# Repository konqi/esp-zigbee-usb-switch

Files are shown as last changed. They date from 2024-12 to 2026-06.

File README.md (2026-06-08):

# zigbee-usb-switch

This project adds zigbee functionality to a USB-Switch.
I used an [ATEN US234](https://www.aten.com/global/en/products/usb-solutions/docks-and-switches/us234/) which you can get on amazon or wherever.
I used this device because it is spacious enough on the inside to fit all the additional components into the case. Other devices should work, but might not be as comfortable to solder and fit everything inside.

# Part List

- A USB Switch that has a toggle button and an LED for each channel. I used [this one](https://www.aten.com/global/en/products/usb-solutions/docks-and-switches/us234/)
- An [Espressif ESP32-C6 DevKitC](https://docs.espressif.com/projects/esp-dev-kits/en/latest/esp32c6/esp32-c6-devkitc-1/user_guide.html#). You can get those very cheap on AliExpress. I recommend you get at least two. One for the finished product, one for the prototyping breadboard.
- (for prototyping) a breadboard and jumper cables
- 3 optocouplers. I used one one LTV827 and one LTV817
- 3 resistors. Depending on your optocoupler and usb switch. I used 330 Ohm for everything
- PCB Board (6x4 cm / 20x14). I used the one from [this set](https://www.az-delivery.de/en/products/pcb-board-set-lochrasterplatte-platine-leiterplatte-4x4-stuck)

# Electronics

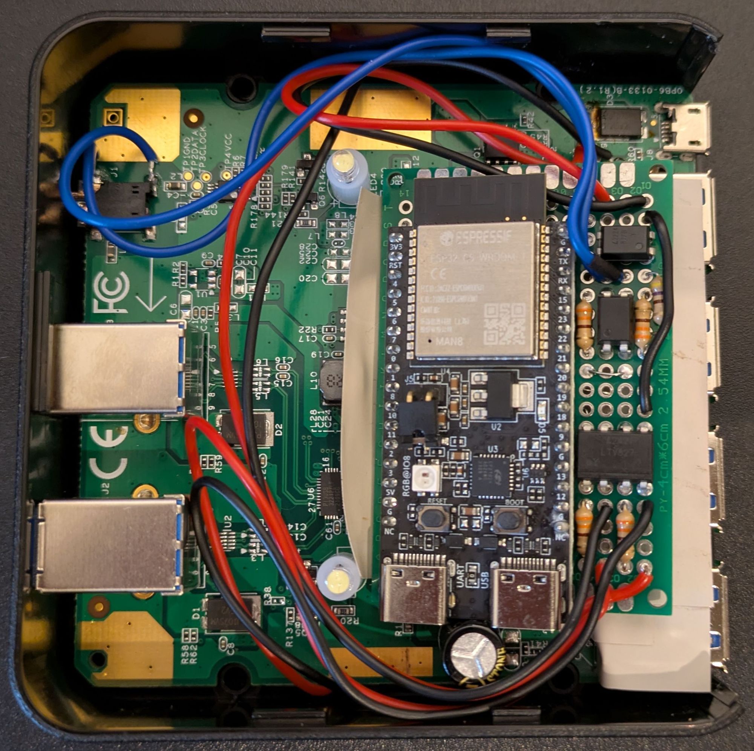
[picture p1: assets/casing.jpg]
casing


Everything fits into the original case. I clipped off everything on the back and put isolating tape wherever physical contact is possible. The two LED sockets and the condensator hold the board in place quite nicely.

## Logic wires

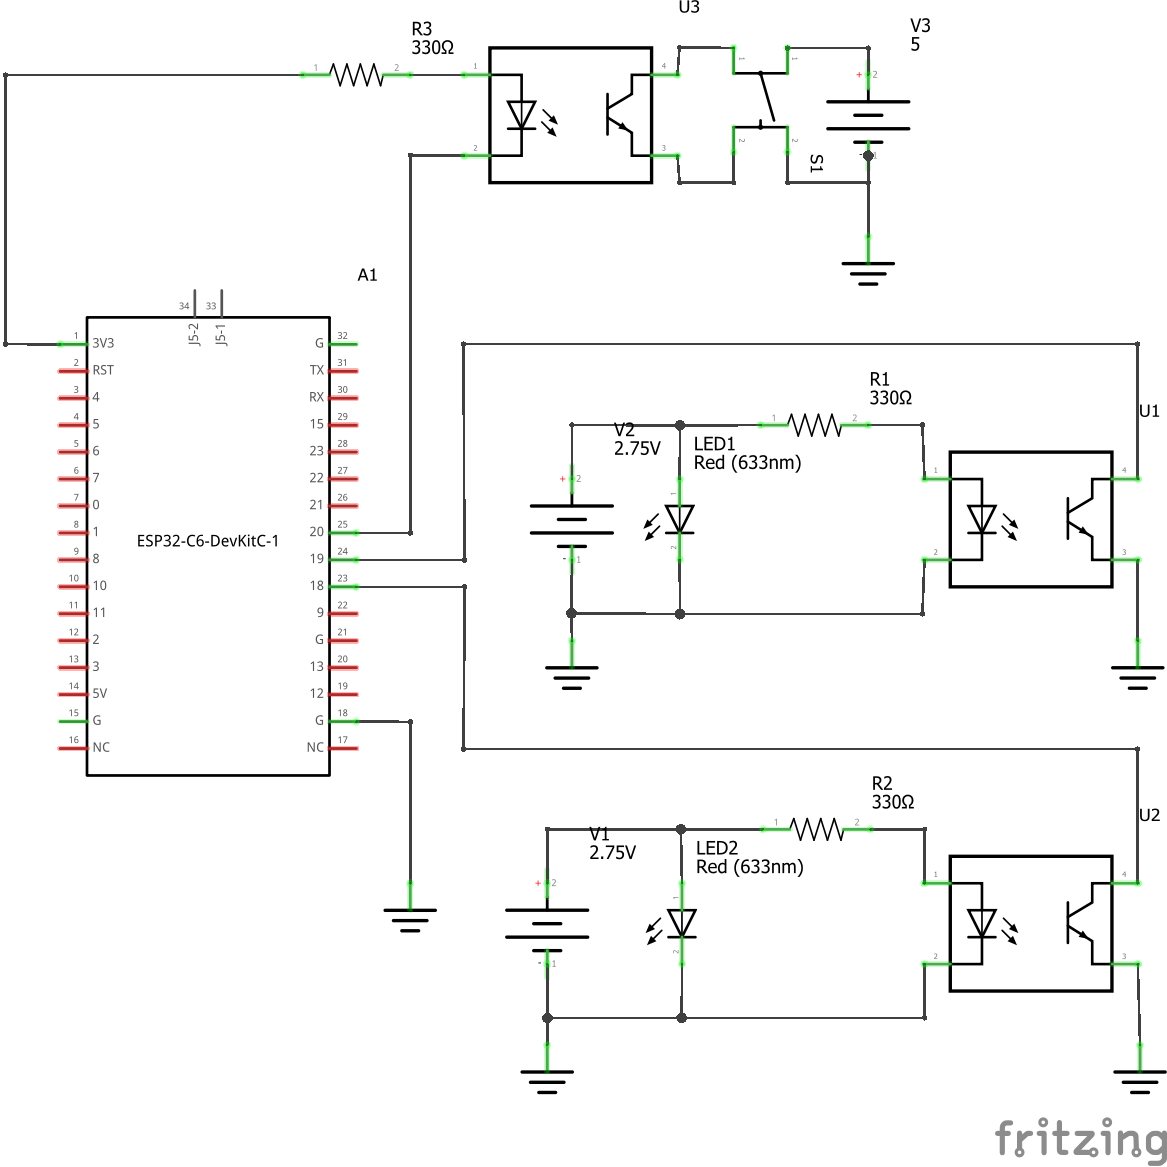
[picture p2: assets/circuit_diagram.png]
circuit diagram


Here is a [Fritzing Schematic](./assets/zigbee-usb-switch.fzz).
You can get the Fritzing App [here](https://fritzing.org/) or [here](https://github.com/fritzing/fritzing-app/releases)

**Note:**
There are a couple of parts in the schematic that represent components on the USB-Switch board:

- LEDs and their corresponding power source are the actual LEDs on the usb switch pcb board. You will need to solder wires to the led pins.
- The button and its power source are in reality a 2,5mm headphone jack on the pcb board

The switch is connected like this:

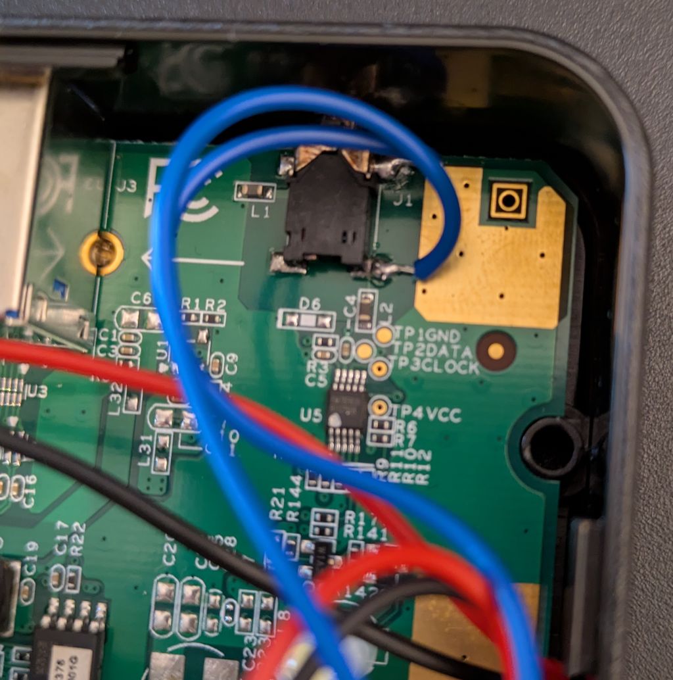
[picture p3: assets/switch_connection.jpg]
switch connect


Current flows from the bottom to the top contact. Make sure that the top pin is connected to the collector of the optocoupler and the lower one to the emitter.

## Power supply

My USB-Switch allows an external power source. I soldered a wire to the copper behind the voltage regulator on the switch pcb. I had to scrape off a bit of coating - seemed easiert than ruining the voltage regulator at the time (my soldering iron is really cheap). Connect the 5V wire to the 5V pin of the ESP32 devkit board.

I soldered ground to the base of one of the USB-Ports, but there are many options for ground. Connect ground to any of the G pins of the ESP32 devkit board.

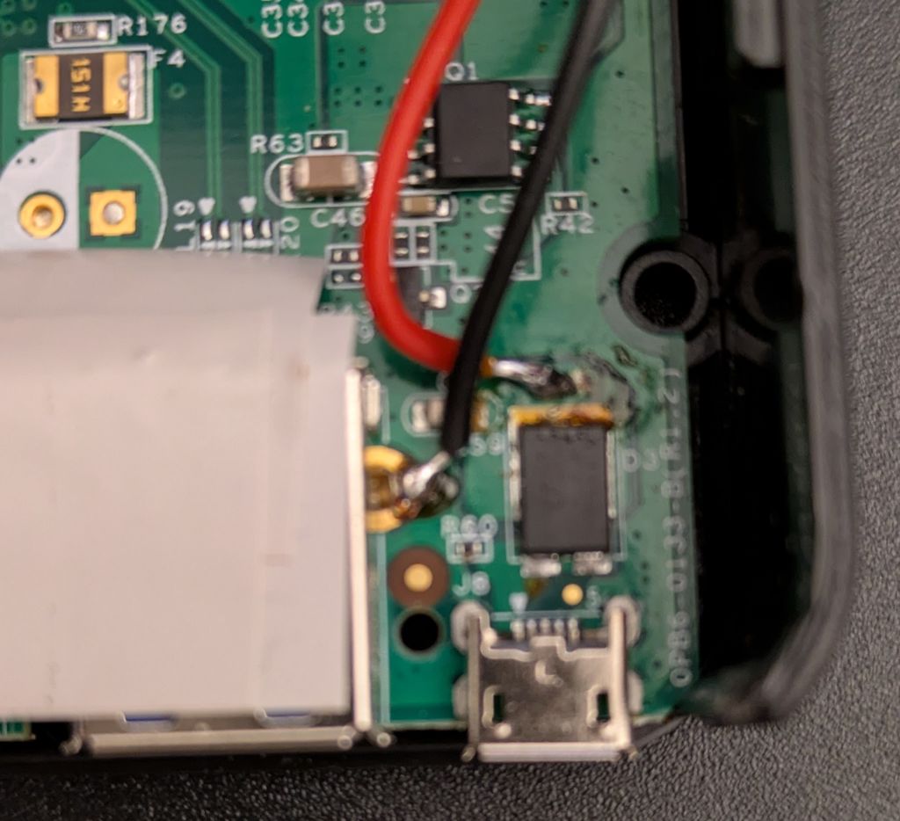
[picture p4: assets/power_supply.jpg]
power supply


# Building and Flashing

Follow the instructions provided by Espressif [see](https://github.com/espressif/esp-zigbee-sdk/tree/main/examples/home_automation_devices/on_off_light).
Personally, I use the ESP-IDF extension in VSCode.
Connect a USB-C cable to the USB-port for programming and monitoring.

Using the cli tools the commands to build and flash should be:

```sh
idf.py set-target esp32c6
idf.py reconfigure
idf.py build
idf.py -p <PORT> flash
```

# Zigbee OTA firmware updates

This firmware is now prepared for Zigbee OTA upgrades:

- OTA client cluster is enabled on endpoint 10
- partition layout includes `ota_0` and `ota_1` slots
- bootloader rollback support is enabled (`CONFIG_BOOTLOADER_APP_ROLLBACK_ENABLE=y`)

When you want to update firmware over Zigbee in the future, you still need an OTA server in your Zigbee network (for example a coordinator/plugin that can host Zigbee OTA images).

The OTA image metadata in firmware is currently:

- manufacturer code: `0x131B`
- image type: `0x0001`
- file version: generated at build time from release/build bytes

By default, the build wiring sets `file version` as:

- app release byte: `1`
- app build byte: `git rev-list --count HEAD` modulo 256
- stack release byte: `0`
- stack build byte: `0`

which is packed as `(app_release << 24) | (app_build << 16) | (stack_release << 8) | stack_build`.

For release builds, you can override values at configure time, for example:

```sh
idf.py -D ESP_OTA_APP_RELEASE=1 -D ESP_OTA_STACK_RELEASE=0 -D ESP_OTA_STACK_BUILD=0 build
```

Your OTA server image metadata must match those values and use a higher file version for updates.

# Integration

If you're using zigbee2mqtt, you can use the converter I created.
Put the [z2m converter file](./z2m_converter/usb-switch.mjs) in your `zigbee2mqtt/data/external_converters` folder.

When this is ever used by more than just one person, I might create a pull-request in the z2m repo for general support.
Doesn't make much sense to do so if it's just me.

## Zigbee OTA updates via zigbee2mqtt

The converter already has `ota: true`. To let zigbee2mqtt find the OTA image, point it at the index file that is updated automatically by the GitHub release workflow.

Add the following to your `zigbee2mqtt/data/configuration.yaml`:

```yaml
ota:
  zigbee_ota_override_index_location: https://raw.githubusercontent.com/konqi/esp-zigbee-usb-switch/main/z2m_converter/ota-index.json
```

Restart zigbee2mqtt. The device will now appear in the **OTA** tab of the zigbee2mqtt frontend. Click **Check for updates** – if a newer firmware is available it will show up, and you can trigger the update from there.

### How releases work

Push a semver tag (e.g. `v1.2.3`) to GitHub. The release workflow will:

1. Build the firmware with OTA version bytes derived from the tag:
   - `APP_RELEASE = 1`, `APP_BUILD = 2`, `STACK_RELEASE = 3`
   - `file_version = (1 << 24) | (2 << 16) | (3 << 8) | 0`
2. Wrap the `.bin` in a Zigbee OTA image (`.ota`).
3. Create a GitHub Release and attach the `.ota` file (old releases are kept).
4. Prepend the new entry to [`z2m_converter/ota-index.json`](./z2m_converter/ota-index.json) and commit it back to `main`.

The raw URL of the index file is stable, so zigbee2mqtt will always fetch the latest list on its next OTA poll.

# Resetting the zigbee connection

Press the toggle button 10 times in short succession.

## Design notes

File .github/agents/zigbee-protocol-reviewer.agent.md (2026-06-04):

---
description: "Use when reviewing Zigbee endpoint/cluster behavior, ZCL attribute handling, reporting configuration, command flow, and firmware logic correctness without making code changes. Keywords: zigbee review, zcl review, cluster validation, endpoint mapping, attribute reporting, behavior audit."
name: "Zigbee Protocol Reviewer"
tools: [read, search, get_errors]
user-invocable: true
---
You are a read-only Zigbee protocol and firmware behavior reviewer.

Your job is to analyze code and configuration for protocol correctness, behavioral regressions, and integration risks, then return prioritized findings.

## Constraints
- DO NOT edit files.
- DO NOT execute terminal commands.
- Focus on correctness, safety, and likely runtime behavior.
- Call out uncertainty explicitly when project context is incomplete.

## Review Priorities
1. Endpoint/cluster consistency and role correctness (server/client placement).
2. ZCL attribute definitions, access permissions, default values, and update paths.
3. Command handling and callback flow for missed states or race conditions.
4. Reporting configuration, binding assumptions, and interoperability risks.
5. Error handling, retries, and boot/pairing edge cases.

## Output Format
Return:
1. Findings (ordered by severity, each with file and reason)
2. Open questions or assumptions
3. Suggested tests to validate behavior

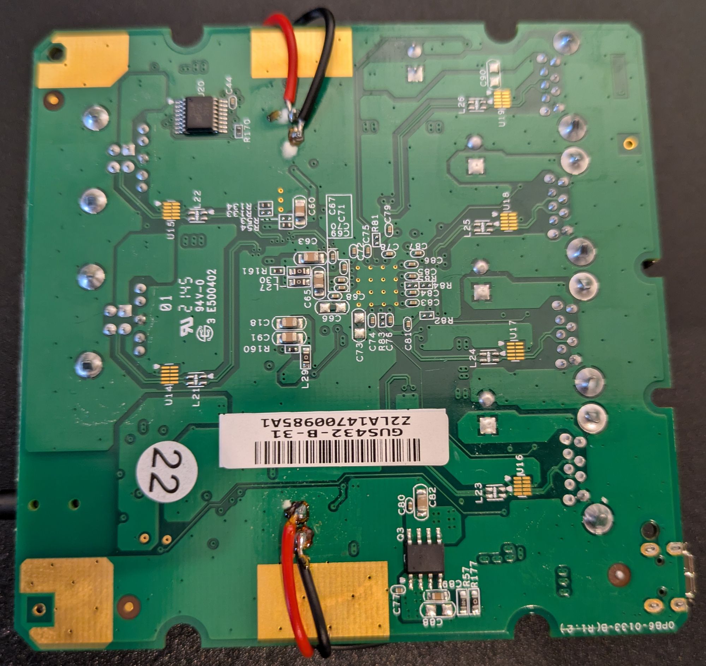
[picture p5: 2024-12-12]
assets/pcb_underside.jpg

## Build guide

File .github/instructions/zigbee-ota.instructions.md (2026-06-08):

---
description: "Reference for the Zigbee OTA update pipeline: firmware versioning, CI release workflow, z2m OTA index, and known constraints. Use when working on OTA versioning, release automation, sdkconfig, or zigbee2mqtt integration."
applyTo: "**/*.yml, z2m_converter/**, main/CMakeLists.txt, CMakeLists.txt, partitions.csv"
name: "Zigbee OTA Pipeline"
---

# Zigbee OTA Pipeline

## Overview

This project supports over-the-air firmware updates via the Zigbee OTA Upgrade cluster
(cluster ID 0x0019). Updates are delivered through zigbee2mqtt (z2m) using a custom OTA
index file hosted on GitHub.

The full pipeline is:

1. Tag is pushed → CI builds firmware → creates `.ota` file → commits updated
   `z2m_converter/ota-index.json` → publishes GitHub Release.
2. z2m polls the custom index URL and compares `fileVersion` against the device's current
   version reported over Zigbee.
3. When a newer version is found, z2m initiates OTA transfer over Zigbee.

---

## OTA File Version Packing

The 32-bit Zigbee OTA `fileVersion` is constructed by the CI release workflow from the
semver release tag `vM.m.p`:

| Byte 3 (MSB) | Byte 2 | Byte 1 | Byte 0 (LSB)  |
| --- | --- | --- | --- |
| `APP_RELEASE` = `(M<<4)\|m` | `APP_BUILD` = `p` | `STACK_RELEASE` | `STACK_BUILD` |

- **App word** (bytes 3–2) encodes major/minor/patch of the product release.
- **Stack word** (bytes 1–0) encodes the Espressif `esp-zigbee-lib` version
  (`major<<4 | minor`, patch) read from
  `managed_components/espressif__esp-zigbee-lib/idf_component.yml` at build time.

Example: tag `v0.1.5` with stack lib `1.6.8` →

```
APP_RELEASE = (0<<4)|1 = 0x01
APP_BUILD   = 5         = 0x05
STACK_RELEASE = (1<<4)|6 = 0x16
STACK_BUILD   = 8         = 0x08
fileVersion = 0x01051608
```

z2m displays this as **App: 0.1 build 5 / Stack: 1.6 build 8**.

**Limits:** major and minor each must fit in 4 bits (max 15). Patch must fit in 8 bits
(max 255). The workflow validates and fails if out of range.

---

## Version Constraints (version monotonicity)

The device only accepts an OTA upgrade if the new `fileVersion` is **numerically greater**
than its current `ota_upgrade_file_version`. Downgrades are rejected at the device level.

This means:

- Bumping major from 0 to 1 produces a massive jump in the packed integer, which is fine.
- Never reuse a version number for a different binary.
- Legacy entries in `ota-index.json` used the old byte packing scheme (raw semver bytes).
  The `create-release-tag` workflow decodes using `decode_from_new_packed` only now;
  legacy `decode_from_legacy_bytes` was removed to prevent incorrect version comparison.

---

## CMake Version Injection

`main/CMakeLists.txt` accepts CMake cache variables at configure time:

| Variable | Default | Description |
| --- | --- | --- |
| `ESP_OTA_APP_RELEASE` | 1 | Packed app release byte (major\|minor) |
| `ESP_OTA_APP_BUILD` | git commit count % 256 | App build/patch byte |
| `ESP_OTA_STACK_RELEASE` | 0 | Stack release byte |
| `ESP_OTA_STACK_BUILD` | 0 | Stack build byte |

CI passes all four explicitly. Local dev builds fall back to the git commit count for
`APP_BUILD` when not specified.

`PROJECT_VER` (CMake-level) is injected from `$ENV{PROJECT_VER}` in `CMakeLists.txt`.
CI sets it to the release tag so the boot log shows e.g. `App version: v0.1.5`.

---

## CI Workflows

### `create-release-tag.yml` (manual dispatch)

- Triggered from GitHub Actions UI with a `bump_part` dropdown: `major`, `minor`, `patch`.
- Computes next semver from max of: latest semver git tag and highest `fileVersion` in
  `ota-index.json` (decoded with the new-packed scheme only).
- Creates and pushes the tag.
- Dispatches `release.yml` via GitHub API (requires `actions: write` permission).

### `release.yml` (tag push or manual dispatch with `release_tag` input)

Steps in order:

1. **Resolve release tag** – uses pushed tag or `release_tag` input.
2. **Parse version** – decodes semver, packs `fileVersion`, validates ranges.
3. **Build firmware** – `espressif/esp-idf-ci-action@v1` with explicit `-D` overrides
   and `PROJECT_VER` env var; target: `esp32c6`; IDF version: `v6.0.1`.
4. **Download OTA image builder** – fetches `image_builder_tool.py` from
   `espressif/esp-zigbee-sdk`.
5. **Create OTA image** – wraps `.bin` in Zigbee OTA format with manufacturer code
   `0x131B` and image type `0x0001`.
6. **Compute checksum** – sha512 + file size.
7. **Fetch release notes** – reads GitHub release body via API.
8. **Update ota-index.json** – prepends new entry, deduplicates by
   `(fileVersion, imageType, manufacturerCode, modelId, manufacturerName)`.
   Adds `releaseNotes` field if release body is non-empty.
9. **Commit ota-index.json** – rebases onto `origin/main` with up to 3 push retries
   to handle concurrent pushes.
10. **Create GitHub Release** – uploads `.ota` asset, generates release notes.

Release creation happens **after** index commit to avoid publishing a stale release if
the commit step fails.

---

## OTA Index (`z2m_converter/ota-index.json`)

Served from GitHub main branch. z2m reads this via `zigbee_ota_override_index_location`
in `configuration.yaml`:

```yaml
ota:
  zigbee_ota_override_index_location: https://raw.githubusercontent.com/konqi/esp-zigbee-usb-switch/main/z2m_converter/ota-index.json
```

Each entry:

```json
{
  "fileVersion":      <uint32>,
  "fileSize":         <bytes>,
  "url":              "https://github.com/konqi/esp-zigbee-usb-switch/releases/download/<tag>/<filename>.ota",
  "imageType":        1,
  "manufacturerCode": 4891,
  "modelId":          "zigbee-usb-switch",
  "manufacturerName": "KONQI",
  "sha512":           "<hex>",
  "releaseNotes":     "<text or empty>"
}
```

`manufacturerCode 4891 = 0x131B`, `imageType 1 = 0x0001`.

---

## Firmware OTA Cluster Configuration

Defined in `main/zigbee_usb_switch.c`:

```c
esp_zb_ota_cluster_cfg_t ota_cfg = {
    .ota_upgrade_file_version = ESP_OTA_FILE_VERSION,  // from CMake
    .ota_upgrade_manufacturer = ESP_OTA_MANUFACTURER_CODE,
    .ota_upgrade_image_type   = ESP_OTA_IMAGE_TYPE,
    ...
};
esp_zb_zcl_ota_upgrade_client_variable_t ota_client_data = {
    .max_data_size = 128,  // max bytes per OTA block request
    ...
};
```

**Note:** `max_data_size` is a device-side maximum advertisement. The actual block size
used during transfer is chosen by the coordinator/z2m, not the device. In practice
z2m/coordinator sends ~50-byte blocks regardless of this setting. This is a coordinator
firmware constraint, not a firmware bug.

OTA query interval is set to `ESP_OTA_QUERY_INTERVAL_MIN` (360 minutes by default) after
joining the network.

---

## Partition Layout

`partitions.csv` defines two OTA app slots:

```
ota_0  app  ota_0  0x20000  928K
ota_1  app  ota_1           928K
```

Current app binary is ~529KB, leaving ~44% headroom. `CONFIG_BOOTLOADER_APP_ROLLBACK_ENABLE=y`
is set so rollback to previous slot is possible on boot failure.

---

## Known Constraints and Gotchas

- **OTA speed** is ~50 bytes/block × ~280ms/block ≈ 50 minutes for a 529KB image. This
  is a coordinator-side limit, not configurable from the device firmware.
- **Downgrade blocked** at device level; version must be numerically larger.
- **Tag trigger limitation**: tags pushed by GITHUB_TOKEN do not trigger `push` events in
  other workflows. This is why `create-release-tag` explicitly dispatches `release.yml`
  via API after pushing the tag.
- **Wi-Fi is disabled** in sdkconfig (not needed for Zigbee-only operation), but LWIP
  and ESP-TLS must remain enabled because transitive dependencies
  (`espressif__esp-zigbee-lib` → `openthread`) require them.
- **sdkconfig vs sdkconfig.defaults**: durable settings go in `sdkconfig.defaults`.
  Machine-generated `sdkconfig` should not be relied on for CI reproducibility.
- **Build type**: CI always builds with the exact committed `sdkconfig.defaults`. Local
  dev builds may differ if `sdkconfig` has uncommitted overrides.

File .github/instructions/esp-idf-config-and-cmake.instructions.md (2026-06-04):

---
description: "Use when editing ESP-IDF build files or configuration such as CMakeLists.txt, *.cmake, sdkconfig defaults, and related component wiring. Covers style and safety conventions for this firmware project."
applyTo: "**/CMakeLists.txt, **/*.cmake, sdkconfig, sdkconfig.defaults, sdkconfig.old"
name: "ESP-IDF Config And CMake Conventions"
---
# ESP-IDF Config and CMake Conventions

- Prefer minimal, targeted changes; avoid broad reformatting in build and config files.
- Preserve existing variable naming and ordering patterns in each CMake file.
- Keep component boundaries explicit with `idf_component_register(...)`; do not add hidden global include paths unless required.
- When adding source files, include only what is needed and keep file lists deterministic.
- Prefer project-local options over global compile definitions unless the setting must affect all components.
- For sdkconfig-related edits, document intent in commit context and avoid toggling unrelated options.
- Treat `sdkconfig.defaults` as the source of durable defaults; avoid relying on machine-specific values in `sdkconfig`.
- If a configuration change can alter flash size, partitions, or boot behavior, call out risk and require explicit validation.
- Keep comments short and practical; explain non-obvious tradeoffs only.
- After changes, validate with build before flash/monitor flows.

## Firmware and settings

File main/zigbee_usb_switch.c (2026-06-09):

/*
 * This code is based on the espressif zigbee home automation (ha) light on/off example
 * The LED ON/OFF functionality is simply left in here, because it's a great way to
 * determine if the zigbee communication works at all.
 */
#include "zigbee_usb_switch.h"
#include "esp_check.h"
#include "esp_err.h"
#include "esp_log.h"
#include "esp_system.h"
#include "nvs_flash.h"
#include "freertos/FreeRTOS.h"
#include "freertos/task.h"
#include "ha/esp_zigbee_ha_standard.h"
#include "esp_zigbee_attribute.h"
#include "ota.h"

#if !defined ZB_ED_ROLE
#error Define ZB_ED_ROLE in idf.py menuconfig to compile light (End Device) source code.
#endif

static const char *TAG = "ESP_ZB_USB_SWITCH";

#define ZB_INVALID_SHORT_ADDR 0xFFFF
#define ZB_STEERING_RETRY_BASE_DELAY_MS 2000
#define ZB_STEERING_RETRY_MAX_DELAY_MS 60000
#define ZB_STEERING_RETRY_MAX_BACKOFF_STEPS 5

#define BUILD_MONTH_IS_JAN (__DATE__[0] == 'J' && __DATE__[1] == 'a' && __DATE__[2] == 'n')
#define BUILD_MONTH_IS_FEB (__DATE__[0] == 'F')
#define BUILD_MONTH_IS_MAR (__DATE__[0] == 'M' && __DATE__[2] == 'r')
#define BUILD_MONTH_IS_APR (__DATE__[0] == 'A' && __DATE__[1] == 'p')
#define BUILD_MONTH_IS_MAY (__DATE__[0] == 'M' && __DATE__[2] == 'y')
#define BUILD_MONTH_IS_JUN (__DATE__[0] == 'J' && __DATE__[2] == 'n')
#define BUILD_MONTH_IS_JUL (__DATE__[0] == 'J' && __DATE__[2] == 'l')
#define BUILD_MONTH_IS_AUG (__DATE__[0] == 'A' && __DATE__[1] == 'u')
#define BUILD_MONTH_IS_SEP (__DATE__[0] == 'S')
#define BUILD_MONTH_IS_OCT (__DATE__[0] == 'O')
#define BUILD_MONTH_IS_NOV (__DATE__[0] == 'N')
#define BUILD_MONTH_IS_DEC (__DATE__[0] == 'D')

#define BUILD_MONTH_CH0 \
    (BUILD_MONTH_IS_OCT || BUILD_MONTH_IS_NOV || BUILD_MONTH_IS_DEC ? '1' : '0')

#define BUILD_MONTH_CH1                                  \
    (BUILD_MONTH_IS_JAN ? '1' : BUILD_MONTH_IS_FEB ? '2' \
                            : BUILD_MONTH_IS_MAR   ? '3' \
                            : BUILD_MONTH_IS_APR   ? '4' \
                            : BUILD_MONTH_IS_MAY   ? '5' \
                            : BUILD_MONTH_IS_JUN   ? '6' \
                            : BUILD_MONTH_IS_JUL   ? '7' \
                            : BUILD_MONTH_IS_AUG   ? '8' \
                            : BUILD_MONTH_IS_SEP   ? '9' \
                            : BUILD_MONTH_IS_OCT   ? '0' \
                            : BUILD_MONTH_IS_NOV   ? '1' \
                                                   : '2')

#define BUILD_DAY_CH0 (__DATE__[4] == ' ' ? '0' : __DATE__[4])
#define BUILD_DAY_CH1 (__DATE__[5])

#define BUILD_DATE_YYYYMMDD {__DATE__[7], __DATE__[8], __DATE__[9], __DATE__[10], BUILD_MONTH_CH0, BUILD_MONTH_CH1, BUILD_DAY_CH0, BUILD_DAY_CH1, '\0'}

#ifndef ESP_SW_BUILD_ID
#define ESP_SW_BUILD_ID "0.0.0"
#endif

static uint8_t s_steering_retry_attempt = 0;
static const char s_build_date_code[] = BUILD_DATE_YYYYMMDD;
static const char s_sw_build_id[] = ESP_SW_BUILD_ID;

static void fill_zcl_string(uint8_t *zb_str, size_t zb_str_size, const char *text)
{
    if (!zb_str || !text || zb_str_size < 2)
    {
        return;
    }

    size_t max_payload = zb_str_size - 1;
    size_t text_len = strlen(text);
    if (text_len > max_payload)
    {
        text_len = max_payload;
    }

    zb_str[0] = (uint8_t)text_len;
    memcpy(&zb_str[1], text, text_len);
}

static void build_basic_cluster_version_strings(uint32_t file_version, uint8_t *sw_build_id, size_t sw_build_id_size,
                                                uint8_t *date_code, size_t date_code_size)
{
    (void)file_version;
    fill_zcl_string(sw_build_id, sw_build_id_size, s_sw_build_id);
    fill_zcl_string(date_code, date_code_size, s_build_date_code);
}

// Note: On my board GPIO_NUM_21 is soldered as input to the external button.
// That experiment didn't work out but I'm too lazy to desolder the IC...
// You don't need to configure GPIO_NUM_21 if it is not connected.
const int gpio_inputs[] = {GPIO_NUM_9, GPIO_NUM_18, GPIO_NUM_19, GPIO_NUM_21};

// this only works as long as gpio_inputs is const
#define INPUT_GPIO_LEN sizeof(gpio_inputs) / sizeof(int)

typedef enum usb_switch_state_enum
{
    CH_1 = 0,
    CH_2 = 1,
    UNKNOWN = 2
} usb_switch_state_t;

static usb_switch_state_t usb_switch_state = UNKNOWN;
static uint8_t reset_counter = 0;

void reset_by_toggle(int gpio_num, gpio_input_state_t value)
{
    if (gpio_num == GPIO_NUM_18 || gpio_num == GPIO_NUM_19)
    {
        if (value == ON_LONG)
        {
            // reset counter
            reset_counter = 0;
        }
        else if (value == ON)
        {
            // increase reset counter
            ++reset_counter;

            if (reset_counter > 10)
            {
                ESP_LOGI(TAG, "Resetting device.");
                esp_zb_factory_reset();
                reset_counter = 0;
            }
        }
    }
}

static void debounced_input_handler(int gpio_num, gpio_input_state_t value)
{
    ESP_LOGI(TAG, "GPIO %i is now %i", gpio_num, value);
    // the following line can be enabled, this effectively creates a flip-flop for the inputs (good for testing connections)
    // toggle_gpio(GPIO_OUTPUT_IO_TOGGLE_SWITCH, 200);

    reset_by_toggle(gpio_num, value);

    if (value == ON)
    {
        usb_switch_state_t new_value = UNKNOWN;
        switch (gpio_num)
        {
        case GPIO_NUM_18:
            new_value = CH_2;
            break;
        case GPIO_NUM_19:
            new_value = CH_1;
            break;
        case GPIO_NUM_9:
            ESP_LOGI(TAG, "Resetting device.");
            esp_zb_factory_reset();
            break;
        default:
            ESP_LOGW(TAG, "Pressing GPIO %i isn't defined.", gpio_num);
            break;
        }

        if (new_value != UNKNOWN)
        {
            usb_switch_state = new_value;
            ESP_LOGI(TAG, "USB Switch state is now %i", new_value);

            esp_zb_lock_acquire(portMAX_DELAY);
            esp_zb_zcl_status_t status = esp_zb_zcl_set_attribute_val(HA_ESP_LIGHT_ENDPOINT,
                                                                      ESP_ZB_ZCL_CLUSTER_ID_MULTI_VALUE,
                                                                      ESP_ZB_ZCL_CLUSTER_SERVER_ROLE,
                                                                      ESP_ZB_ZCL_ATTR_MULTI_VALUE_PRESENT_VALUE_ID,
                                                                      &new_value,
                                                                      false);
            esp_zb_lock_release();
            ESP_LOGI(TAG, "Multistate value updated to %i, status %i", new_value, status);

            // manual report of attribute (not necessary)
            // esp_zb_zcl_report_attr_cmd_t report_attr_cmd = {
            //     .address_mode = ESP_ZB_APS_ADDR_MODE_DST_ADDR_ENDP_NOT_PRESENT,
            //     .clusterID = ESP_ZB_ZCL_CLUSTER_ID_MULTI_VALUE,
            //     .attributeID = ESP_ZB_ZCL_ATTR_MULTI_VALUE_PRESENT_VALUE_ID,
            //     .direction = ESP_ZB_ZCL_CMD_DIRECTION_TO_SRV, // ESP_ZB_ZCL_CMD_DIRECTION_TO_CLI,
            //     .zcl_basic_cmd.src_endpoint = HA_ESP_LIGHT_ENDPOINT,
            // };

            // esp_zb_lock_acquire(portMAX_DELAY);
            // ESP_ERROR_CHECK_WITHOUT_ABORT(esp_zb_zcl_report_attr_cmd_req(&report_attr_cmd));
            // esp_zb_lock_release();
            // ESP_LOGI(TAG, "Multistate value reported");
        }
    }
}

static esp_err_t deferred_driver_init(void)
{
    static bool is_inited = false;

    ESP_RETURN_ON_FALSE(!is_inited, ESP_OK, TAG, "Deferred driver already initialized");

    light_driver_init(LIGHT_DEFAULT_OFF);
    // ESP_RETURN_ON_FALSE(switch_driver_init(button_func_pair, PAIR_SIZE(button_func_pair), zb_buttons_handler), ESP_FAIL, TAG,
    //                     "Failed to initialize switch driver");
    ESP_LOGI(TAG, "Configuring %i pins for input", INPUT_GPIO_LEN);
    ESP_RETURN_ON_ERROR(gpio_debounce_input_init(gpio_inputs, INPUT_GPIO_LEN, debounced_input_handler), TAG, "Failed to initialize debounced inputs.");
    ESP_RETURN_ON_ERROR(toggle_driver_gpio_init(GPIO_OUTPUT_IO_TOGGLE_SWITCH), TAG,
                        "Failed to initialize toggle driver");
    is_inited = true;

    return ESP_OK;
}

static void bdb_start_top_level_commissioning_cb(uint8_t mode_mask)
{
    esp_err_t err = esp_zb_bdb_start_top_level_commissioning(mode_mask);
    if (err != ESP_OK)
    {
        ESP_LOGW(TAG, "Failed to start Zigbee commissioning (status: %s)", esp_err_to_name(err));
    }
}

static void schedule_steering_retry(const char *reason)
{
    uint32_t backoff_step = s_steering_retry_attempt;
    if (backoff_step > ZB_STEERING_RETRY_MAX_BACKOFF_STEPS)
    {
        backoff_step = ZB_STEERING_RETRY_MAX_BACKOFF_STEPS;
    }

    uint32_t delay_ms = ZB_STEERING_RETRY_BASE_DELAY_MS << backoff_step;
    if (delay_ms > ZB_STEERING_RETRY_MAX_DELAY_MS)
    {
        delay_ms = ZB_STEERING_RETRY_MAX_DELAY_MS;
    }

    ESP_LOGW(TAG, "Scheduling steering retry #%u in %lu ms (%s)",
             (unsigned int)(s_steering_retry_attempt + 1), (unsigned long)delay_ms,
             reason ? reason : "no reason");

    esp_zb_scheduler_alarm((esp_zb_callback_t)bdb_start_top_level_commissioning_cb,
                           ESP_ZB_BDB_MODE_NETWORK_STEERING,
                           delay_ms);

    if (s_steering_retry_attempt < 255)
    {
        s_steering_retry_attempt++;
    }
}

void esp_zb_app_signal_handler(esp_zb_app_signal_t *signal_struct)
{
    uint32_t *p_sg_p = signal_struct->p_app_signal;
    esp_err_t err_status = signal_struct->esp_err_status;
    esp_zb_app_signal_type_t sig_type = *p_sg_p;
    switch (sig_type)
    {
    case ESP_ZB_ZDO_SIGNAL_SKIP_STARTUP:
        ESP_LOGI(TAG, "Initialize Zigbee stack");
        esp_zb_bdb_start_top_level_commissioning(ESP_ZB_BDB_MODE_INITIALIZATION);
        break;
    case ESP_ZB_BDB_SIGNAL_DEVICE_FIRST_START:
    case ESP_ZB_BDB_SIGNAL_DEVICE_REBOOT:
        if (err_status == ESP_OK)
        {
            ESP_LOGI(TAG, "Deferred driver initialization %s", deferred_driver_init() ? "failed" : "successful");
            ESP_LOGI(TAG, "Device started up in %s factory-reset mode", esp_zb_bdb_is_factory_new() ? "" : "non");
            if (esp_zb_bdb_is_factory_new())
            {
                s_steering_retry_attempt = 0;
                ESP_LOGI(TAG, "Start network steering");
                esp_zb_bdb_start_top_level_commissioning(ESP_ZB_BDB_MODE_NETWORK_STEERING);
            }
            else
            {
                uint16_t short_addr = esp_zb_get_short_address();
                if (short_addr == ZB_INVALID_SHORT_ADDR)
                {
                    ESP_LOGW(TAG, "Device rebooted but is not joined yet, starting recovery steering");
                    schedule_steering_retry("reboot without network");
                }
                else
                {
                    s_steering_retry_attempt = 0;
                    ESP_LOGI(TAG, "Device rebooted and restored network (PAN ID: 0x%04hx, Channel:%d, Short Address: 0x%04hx)",
                             esp_zb_get_pan_id(), esp_zb_get_current_channel(), short_addr);
                    ota_configure_query_interval(HA_ESP_LIGHT_ENDPOINT);
                }
            }
        }
        else
        {
            /* commissioning failed */
            ESP_LOGW(TAG, "Failed to initialize Zigbee stack (status: %s)", esp_err_to_name(err_status));
            schedule_steering_retry("stack initialization failed");
        }
        break;
    case ESP_ZB_BDB_SIGNAL_STEERING:
        if (err_status == ESP_OK)
        {
            s_steering_retry_attempt = 0;
            esp_zb_ieee_addr_t extended_pan_id;
            esp_zb_get_extended_pan_id(extended_pan_id);
            ESP_LOGI(TAG, "Joined network successfully (Extended PAN ID: %02x:%02x:%02x:%02x:%02x:%02x:%02x:%02x, PAN ID: 0x%04hx, Channel:%d, Short Address: 0x%04hx)",
                     extended_pan_id[7], extended_pan_id[6], extended_pan_id[5], extended_pan_id[4],
                     extended_pan_id[3], extended_pan_id[2], extended_pan_id[1], extended_pan_id[0],
                     esp_zb_get_pan_id(), esp_zb_get_current_channel(), esp_zb_get_short_address());

            ota_configure_query_interval(HA_ESP_LIGHT_ENDPOINT);

            // read values once after zigbee initialization
            gpio_read_once();
        }
        else
        {
            ESP_LOGI(TAG, "Network steering was not successful (status: %s)", esp_err_to_name(err_status));
            schedule_steering_retry("network steering failed");
        }
        break;
    case ESP_ZB_ZDO_SIGNAL_DEVICE_ANNCE:
    {
        const esp_zb_zdo_signal_device_annce_params_t *dev_annce = (const esp_zb_zdo_signal_device_annce_params_t *)esp_zb_app_signal_get_params(p_sg_p);
        if (dev_annce)
        {
            ESP_LOGI(TAG, "New device commissioned or rejoined (short: 0x%04hx)", dev_annce->device_short_addr);
        }
        break;
    }
    case ESP_ZB_NWK_SIGNAL_PERMIT_JOIN_STATUS:
    {
        const uint8_t *duration = (const uint8_t *)esp_zb_app_signal_get_params(p_sg_p);
        if (duration && *duration)
        {
            ESP_LOGI(TAG, "Network(0x%04hx) is open for %d seconds", esp_zb_get_pan_id(), *duration);
        }
        else
        {
            ESP_LOGI(TAG, "Network(0x%04hx) closed, devices joining not allowed", esp_zb_get_pan_id());
        }
        break;
    }
    default:
        ESP_LOGI(TAG, "ZDO signal: %s (0x%x), status: %s", esp_zb_zdo_signal_to_string(sig_type), sig_type,
                 esp_err_to_name(err_status));
        break;
    }
}

static esp_err_t zb_attribute_handler(const esp_zb_zcl_set_attr_value_message_t *message)
{
    esp_err_t ret = ESP_OK;
    bool light_state = 0;

    ESP_RETURN_ON_FALSE(message, ESP_FAIL, TAG, "Empty message");
    ESP_RETURN_ON_FALSE(message->info.status == ESP_ZB_ZCL_STATUS_SUCCESS, ESP_ERR_INVALID_ARG, TAG, "Received message: error status(%d)",
                        message->info.status);
    ESP_LOGI(TAG, "Received message: endpoint(%d), cluster(0x%x), attribute(0x%x), data size(%d)", message->info.dst_endpoint, message->info.cluster,
             message->attribute.id, message->attribute.data.size);
    if (message->info.dst_endpoint == HA_ESP_LIGHT_ENDPOINT)
    {
        if (message->info.cluster == ESP_ZB_ZCL_CLUSTER_ID_MULTI_VALUE && message->attribute.id == ESP_ZB_ZCL_ATTR_MULTI_VALUE_PRESENT_VALUE_ID)
        {
            // determine value
            uint16_t desired_state = *(uint16_t *)message->attribute.data.value;
            ESP_LOGI(TAG, "Received state change to value %i", desired_state);
            // check if toggle is required
            if (desired_state != usb_switch_state)
            {
                ESP_LOGI(TAG, "Switch not in desired state. Toggeling");
                toggle_gpio(GPIO_OUTPUT_IO_TOGGLE_SWITCH, 200);
            }
        }
        else if (message->info.cluster == ESP_ZB_ZCL_CLUSTER_ID_ON_OFF)
        {
            if (message->attribute.id == ESP_ZB_ZCL_ATTR_ON_OFF_ON_OFF_ID && message->attribute.data.type == ESP_ZB_ZCL_ATTR_TYPE_BOOL)
            {
                light_state = message->attribute.data.value ? *(bool *)message->attribute.data.value : light_state;
                ESP_LOGI(TAG, "Light sets to %s", light_state ? "On" : "Off");
                light_driver_set_power(light_state);
            }
        }
    }

    return ret;
}

static esp_err_t zb_action_handler(esp_zb_core_action_callback_id_t callback_id, const void *message)
{
    esp_err_t ret = ESP_OK;
    switch (callback_id)
    {
    case ESP_ZB_CORE_SET_ATTR_VALUE_CB_ID:
        ret = zb_attribute_handler((esp_zb_zcl_set_attr_value_message_t *)message);
        break;
    case ESP_ZB_CORE_CMD_DEFAULT_RESP_CB_ID:
        esp_zb_zcl_cmd_default_resp_message_t *msg = (esp_zb_zcl_cmd_default_resp_message_t *)message;
        // cmd 10 = report attributes
        ESP_LOGI(TAG, "Received reponse (0x%02x) to cmd(0x%02x) endpoint(%i) cluster(%i) status(0x%02x)",
                 ESP_ZB_CORE_CMD_DEFAULT_RESP_CB_ID,
                 msg->resp_to_cmd,
                 msg->info.dst_endpoint,
                 msg->info.cluster,
                 msg->info.status);
        break;
    case ESP_ZB_CORE_SCENES_STORE_SCENE_CB_ID:
    {
        const esp_zb_zcl_store_scene_message_t *scene = (const esp_zb_zcl_store_scene_message_t *)message;
        if (scene->info.status != ESP_ZB_ZCL_STATUS_SUCCESS)
        {
            ESP_LOGW(TAG, "Scenes store callback status not successful (0x%02x)", scene->info.status);
            break;
        }

        uint16_t scene_state = (uint16_t)usb_switch_state;
        uint8_t ext_value[sizeof(uint16_t)] = {
            (uint8_t)(scene_state & 0xFF),
            (uint8_t)((scene_state >> 8) & 0xFF),
        };
        esp_zb_zcl_scenes_extension_field_t ext_field = {
            .cluster_id = ESP_ZB_ZCL_CLUSTER_ID_MULTI_VALUE,
            .length = sizeof(uint16_t),
            .extension_field_attribute_value_list = ext_value,
            .next = NULL,
        };

        esp_err_t scene_ret = esp_zb_zcl_scenes_table_store(HA_ESP_LIGHT_ENDPOINT,
                                                            scene->group_id,
                                                            scene->scene_id,
                                                            0,
                                                            &ext_field);
        ESP_LOGI(TAG, "Stored scene %u/%u with multi-value=%u (%s)",
                 scene->group_id,
                 scene->scene_id,
                 scene_state,
                 scene_ret == ESP_OK ? "ok" : esp_err_to_name(scene_ret));
        break;
    }
    case ESP_ZB_CORE_SCENES_RECALL_SCENE_CB_ID:
    {
        const esp_zb_zcl_recall_scene_message_t *scene = (const esp_zb_zcl_recall_scene_message_t *)message;
        if (scene->info.status != ESP_ZB_ZCL_STATUS_SUCCESS)
        {
            ESP_LOGW(TAG, "Scenes recall callback status not successful (0x%02x)", scene->info.status);
            break;
        }

        const esp_zb_zcl_scenes_extension_field_t *field = scene->field_set;
        while (field)
        {
            if (field->cluster_id == ESP_ZB_ZCL_CLUSTER_ID_MULTI_VALUE &&
                field->extension_field_attribute_value_list &&
                field->length >= sizeof(uint16_t))
            {
                uint16_t desired_state = (uint16_t)field->extension_field_attribute_value_list[0] |
                                         ((uint16_t)field->extension_field_attribute_value_list[1] << 8);
                ESP_LOGI(TAG, "Recall scene %u/%u contains multi-value=%u", scene->group_id, scene->scene_id, desired_state);
                if ((usb_switch_state_t)desired_state != usb_switch_state)
                {
                    ESP_LOGI(TAG, "Applying recalled multi-value state by toggling switch");
                    toggle_gpio(GPIO_OUTPUT_IO_TOGGLE_SWITCH, 200);
                }
                break;
            }
            field = field->next;
        }
        break;
    }
    case ESP_ZB_CORE_OTA_UPGRADE_VALUE_CB_ID:
        ota_handle_upgrade_value(message);
        break;
    case ESP_ZB_CORE_OTA_UPGRADE_QUERY_IMAGE_RESP_CB_ID:
        ota_handle_query_image_resp(message);
        break;
    default:
        ESP_LOGW(TAG, "Receive Zigbee action(0x%02x) callback", callback_id);
        break;
    }
    return ret;
}
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
void app_main(void)
{
    esp_zb_platform_config_t config = {
        .radio_config = ESP_ZB_DEFAULT_RADIO_CONFIG(),
        .host_config = ESP_ZB_DEFAULT_HOST_CONFIG(),
    };
    ESP_LOGI(TAG, "Reset reason: %d", (int)esp_reset_reason());
    ota_log_partition_state("Boot before confirm");
    ota_confirm_image_if_pending();
    ota_log_partition_state("Boot after confirm");
    ESP_ERROR_CHECK(nvs_flash_init());
    ESP_ERROR_CHECK(esp_zb_platform_config(&config));
    xTaskCreate(esp_zb_task, "Zigbee_main", 4096, NULL, 5, NULL);
}

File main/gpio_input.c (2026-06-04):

#include "esp_log.h"
#include "esp_check.h"
#include "esp_err.h"
#include "freertos/FreeRTOS.h"
#include "freertos/task.h"
#include "gpio_input.h"

static const char *TAG = "GPIO_DEBOUNCED_INPUT";

static uint8_t gpio_count = 0;
static gpio_input_debounce_config_t *internal_config = NULL; /* pointer to array */
static debounced_input_callback callback = NULL;

TaskHandle_t loop_task_handle = NULL;

static void IRAM_ATTR gpio_interrupt_handler(void *arg)
{
    gpio_input_debounce_config_t *input_debounce_helper = arg;
    input_debounce_helper->interrupt_cnt++;
    input_debounce_helper->last_state = gpio_get_level(input_debounce_helper->gpio_num);
    input_debounce_helper->debounce_timeout = xTaskGetTickCountFromISR();
}

static const uint16_t debounce_loop_delay_ticks = 50 / portTICK_PERIOD_MS;
static void debounce_gpio_input_loop_task(void *arg)
{
    // FreeRTOS task entry requires this parameter, even though this task does not use it.
    (void)arg;
    for (;;)
    {
        for (int i = 0; i < gpio_count; ++i)
        {
            gpio_input_debounce_config_t *gpio_helper = &(internal_config[i]);
            int gpio_num = gpio_helper->gpio_num;
            gpio_input_state_t gpio_state = gpio_get_level(gpio_num);

            if ( // interrupt triggerd
                gpio_helper->interrupt_cnt != 0 &&
                // the input is still in the same state
                gpio_state == gpio_helper->last_state &&
                // check debounce time has expired
                (xTaskGetTickCount() - gpio_helper->debounce_timeout > DEBOUNCE_TICKS))
            {
                // gpio_state is stable
                ESP_LOGD(TAG, "gpio %i apprears to be stable in state %i", gpio_num, gpio_state);

                // trigger callback
                callback(gpio_num, gpio_state);

                // reset
                gpio_helper->interrupt_cnt = 0;
            }

            if ( // no other interrupt was triggered (button still pressed)
                gpio_helper->interrupt_cnt == 0 &&
                // long enough for a long press
                (xTaskGetTickCount() - gpio_helper->debounce_timeout > LONG_PRESS_TICKS) &&
                // only trigger once
                (xTaskGetTickCount() - gpio_helper->debounce_timeout < LONG_PRESS_TICKS + debounce_loop_delay_ticks))
            {
                ESP_LOGV(TAG, "long stable state on gpio %i in state %i", gpio_num, gpio_state);

                // trigger callback
                callback(gpio_num, gpio_state + 2);
            }
        }

        vTaskDelay(debounce_loop_delay_ticks);
    }
}

static esp_err_t configure_gpio_inputs(const int gpio_nums[])
{
    gpio_config_t io_conf = {};
    uint64_t pin_bit_mask = 0;

    /* construct bitmask to configure potentially multiple gpios */
    for (int i = 0; i < gpio_count; ++i)
    {
        pin_bit_mask |= (1ULL << gpio_nums[i]);
    }
    /* interrupt on all edges */
    io_conf.intr_type = GPIO_INTR_ANYEDGE;
    io_conf.pin_bit_mask = pin_bit_mask;
    io_conf.mode = GPIO_MODE_INPUT;
    io_conf.pull_down_en = 0;
    io_conf.pull_up_en = 1;

    /* configure GPIO with the given settings */
    ESP_RETURN_ON_ERROR(gpio_config(&io_conf), TAG, "Unable to configure GPIOs.");

    return ESP_OK;
}

static void clean_up()
{
    if (gpio_count > 0)
    {
        // free previously allocated memory
        free(internal_config);
    }
    if (loop_task_handle != NULL)
    {
        // remove previously started task
        vTaskDelete(loop_task_handle);
    }
}
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

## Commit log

2024-11-23 add output toggle for switch
2024-12-02 fix multistate cluster for state
    [esp_zb_light.c, esp_zb_light.h]
2024-12-10 add actual switcher logic
2024-12-11 add reset via toggeling 10 times
    [esp_zb_light.c]
2024-12-12 adjust readme
    [zigbee-usb-switch.fzz]
2024-12-13 fixed incorrect schematic
    [zigbee-usb-switch.fzz]
2026-06-08 init ota
    [partitions.csv]
2026-06-08 optimize OTA (BREAKING CHANGE)
    [partitions.csv]
2026-06-09 fix OTA update lost after power cycle
    [zigbee_usb_switch.c]
